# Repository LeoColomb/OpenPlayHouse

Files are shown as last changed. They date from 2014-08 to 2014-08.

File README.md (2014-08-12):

OPH-logo (http://ldworkshop.fr/oph.html)

[Open Play House](http://ldworkshop.fr/oph.html)
=================



About
-----

OpenPlayHouse (OPH for fast typing) is an Open Hardware project launched by LD
Workshop.  
LD Workshop is a maker place where you can lasercut, 3D print and create every
idea you have in mind. Located in France (Saint-Étienne), this workshop has
started in 2013 and is owned by Loyc DESFARGES (me). OPH idea is born because,
as many makers, I have kids who love to play, play, and... play. So I decided
to creat this kind of dollhouse you can make, paint, personnalize, modify...
As it's an open hardware project, feel free to use it, share it and make it
better! Please don't forget to share your improvments, new furnitures,
corrections with me at oph@ldworkshop.fr.

---

OPH is to be made of MDF (Medium Density Fiber wood). Of course, feel free to
try it with any other material. My drawings are optimized for 3 mm thickness
MDF. If you want to cutit in another thikness, you will have to correct size of
every hole where another piece will be inserted.  
As I have a laser-cutter, I designed this project to be lasercut. If you don't
own a laser-cutter, I'm sure you can go to your local maker place, Fab-Lab,
workshop... with the PDF files. Each PDF files is a vector file, it means you
can import it in a vector software to use it with a laser-cutter.  
Some furniture parts must be 3Dprint. Same thing, if you don't have a 3D
printer, I'm sure you can find one locally.  
If you can't find anyone able to lasercut and 3D print, LD Workshop can do it
for you and ship the pieces.

Have fun creating the OPH and I hope your kids will have as much fun playing
with it.

Bill of material
----------------
To create an OPH, you'll need :
* A laser cutter.
* 3 mm MDF (Medium Density Fiber wood) – approx. 1000 mm x 1500 mm.
* 3 mm acrylic (transparent and opaque acrylic are used) – approx. 100 mm x 300
  mm. For some furniture (TV for example, 2mm acrylic is advised but 3mm can
  work too)
* Black cardboard 0,3 to 1mm thick – Approx 100 mm x 100 mm.
* A 3D printer (I used PLA filament but you can do it with other material)
* Some papersand (a thin one: about 80-120)
* Wood glue to assemble MDF parts
* Regular hobby glue (multi-use glue) to assemble acrylic and PLA parts
* for the main door, you will need to drill a very small hole (approx 1mm
  diameter)
* 2 small nails
* Paint, brushes, wall paper... and whatever you want to use to personalize your
  OPH.

Drawings
--------
You can find every needed drawings into the `STL` folder.
OpenPlayHouse.skp file includes 3D views of all part, 2D views and instructions.
To open this file, you'll need Sketchup Make http://www.sketchup.com/download.

* STL files are for 3D printing.
* PDF files contains vector drawings and instructions.

If you see any mistake in those drawings, thank you for letting me know.

License
-------
This project is licensed under __Creative Commons__  
Attribution (BY) - Non commercial - Share Alike

OPH is an Open Hardware Project by Loyc DESFARGES <oph@ldworkshop.fr>

> LD Workshop  
> 4 rue du Grand Gonnet  
> 42000 Saint Etienne  
> France  
> www.ldworkhsop.fr

Special thanks to my wife and kids who are my inspiration, helps and
beta-testers.

Changelog
---------
* __v1.03__: vcs with git, markdownify README, versions by tag
* __v1.02__: add sofa in the .skp file and sofa drawings in the PDF folder.

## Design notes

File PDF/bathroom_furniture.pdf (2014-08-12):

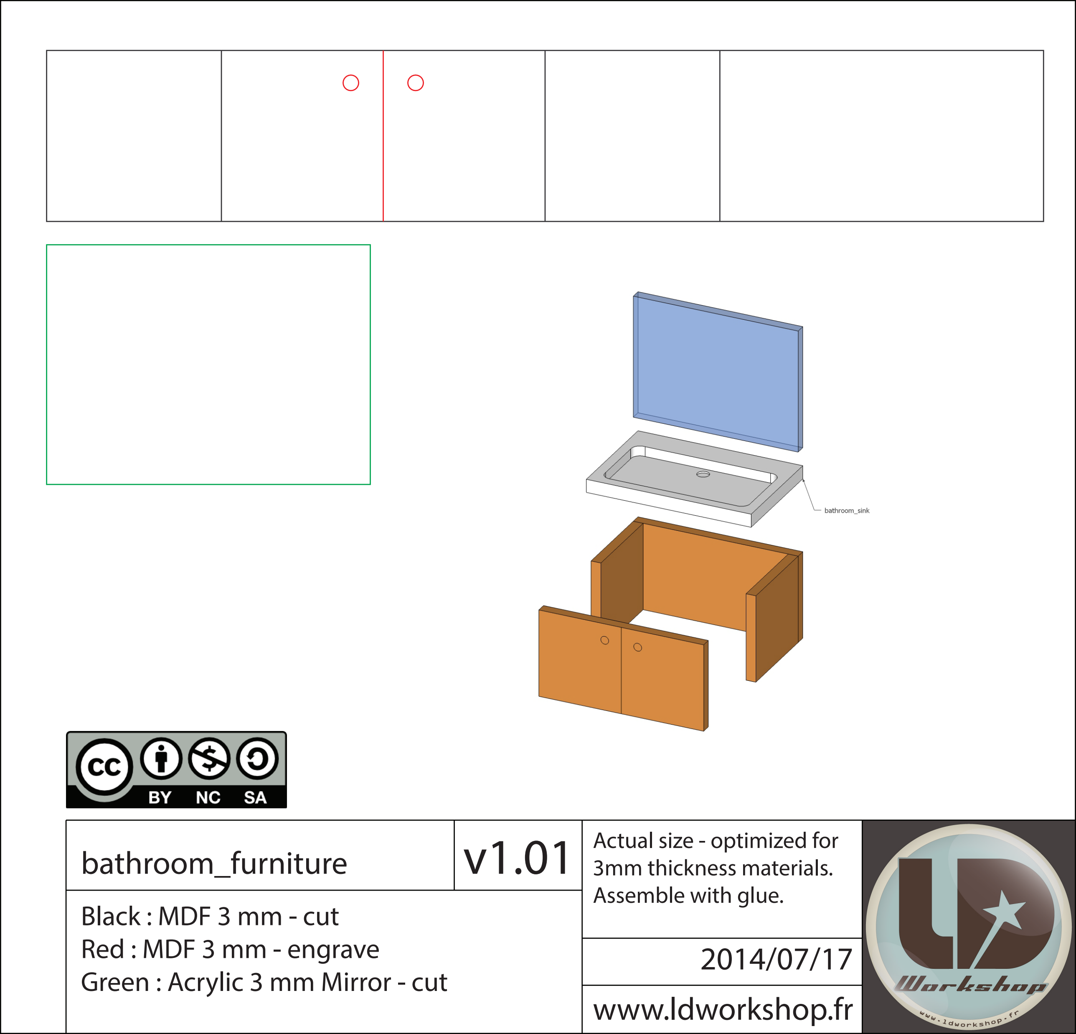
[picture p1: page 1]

bathroom_furniture
Black : MDF 3 mm - cut
Red : MDF 3 mm - engrave
Green : Acrylic 3 mm Mirror - cut

Actual size - optimized for 3mm thickness materials.
Assemble with glue.

www.ldworkshop.fr

2014/07/17

v1.01

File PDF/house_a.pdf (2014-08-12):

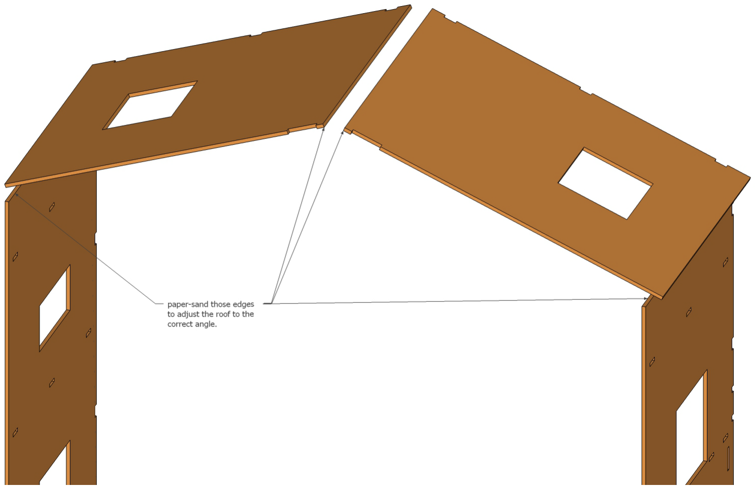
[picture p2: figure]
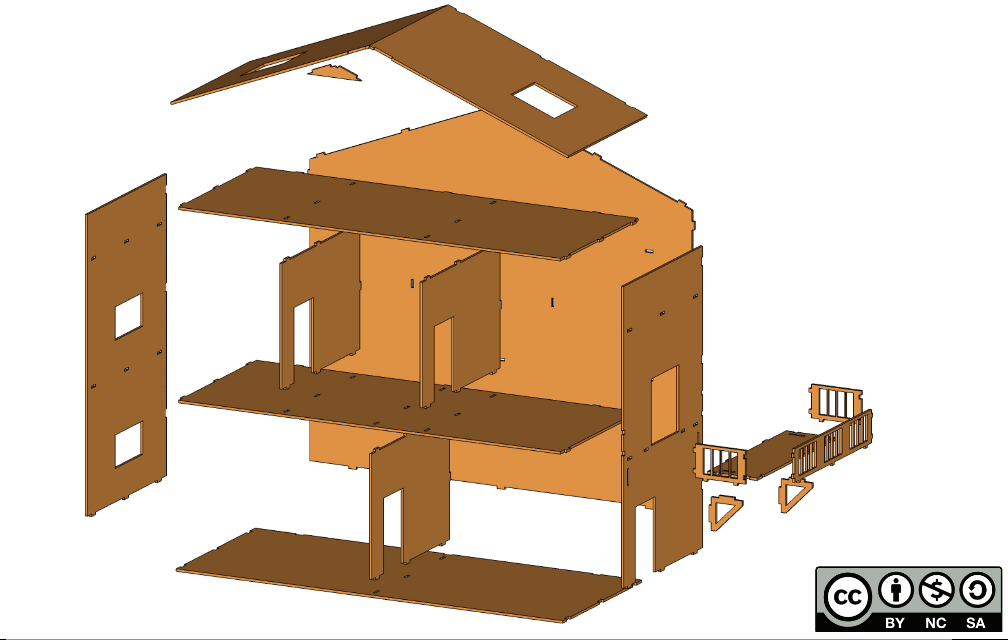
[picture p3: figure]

## house_a

### Black : MDF 3 mm - cut

Actual size - optimized for 3mm thickness materials.
Assemble with glue.

## www.ldworkshop.fr

2014/07/17

v1.01

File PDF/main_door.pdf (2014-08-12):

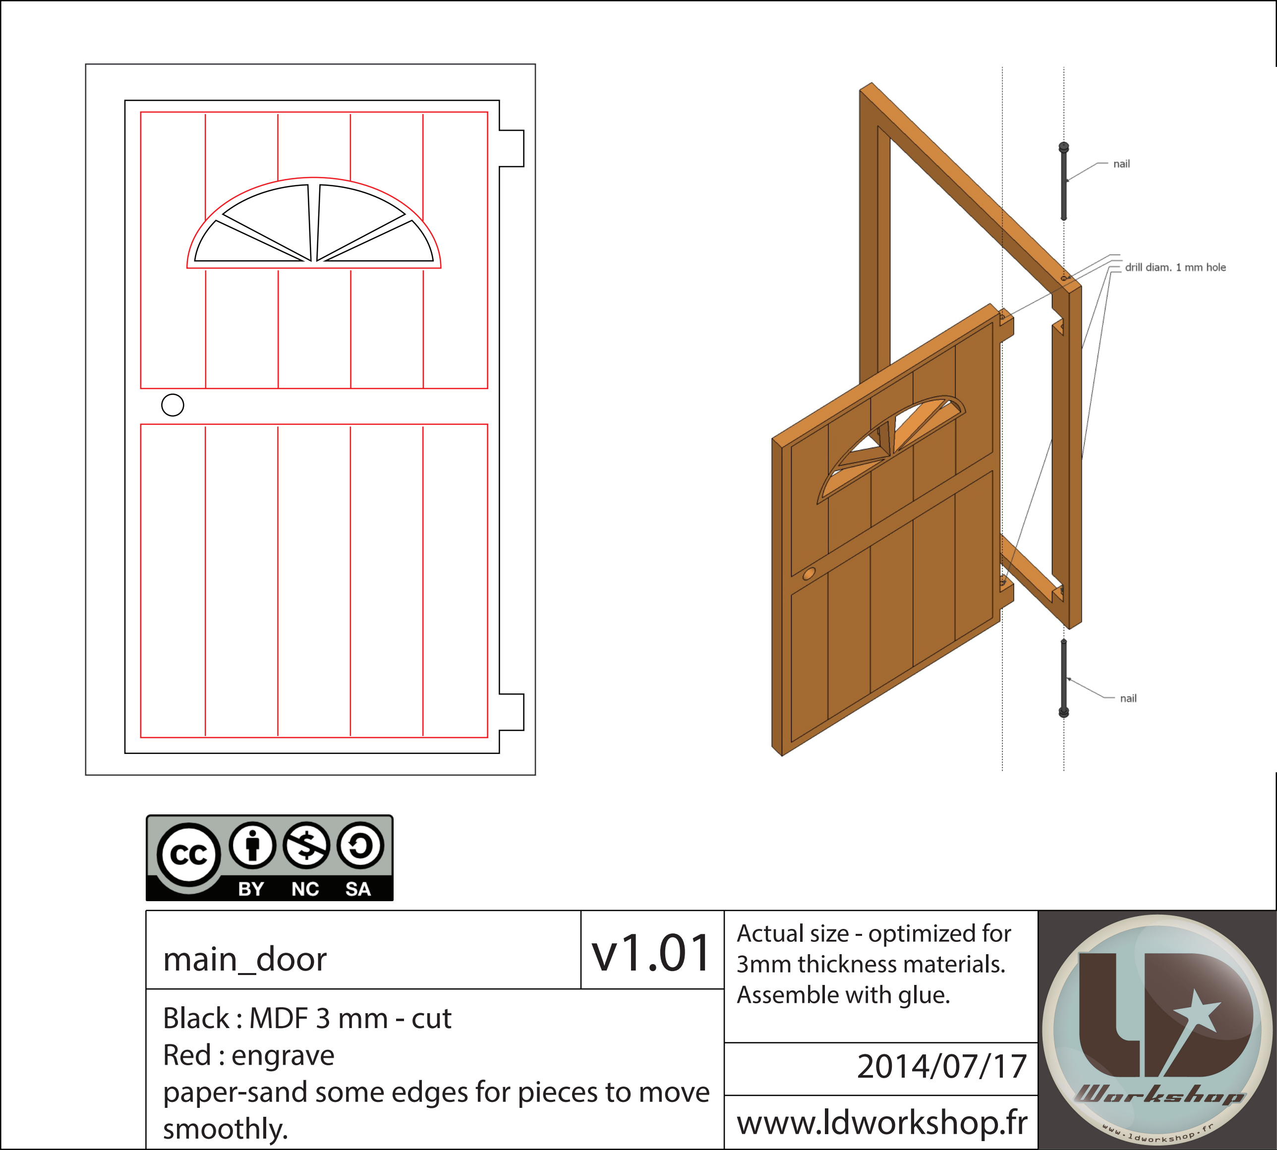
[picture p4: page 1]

main_door
Black : MDF 3 mm - cut
Red : engrave
paper-sand some edges for pieces to move smoothly.

Actual size - optimized for 3mm thickness materials.
Assemble with glue.

www.ldworkshop.fr

2014/07/17

v1.01

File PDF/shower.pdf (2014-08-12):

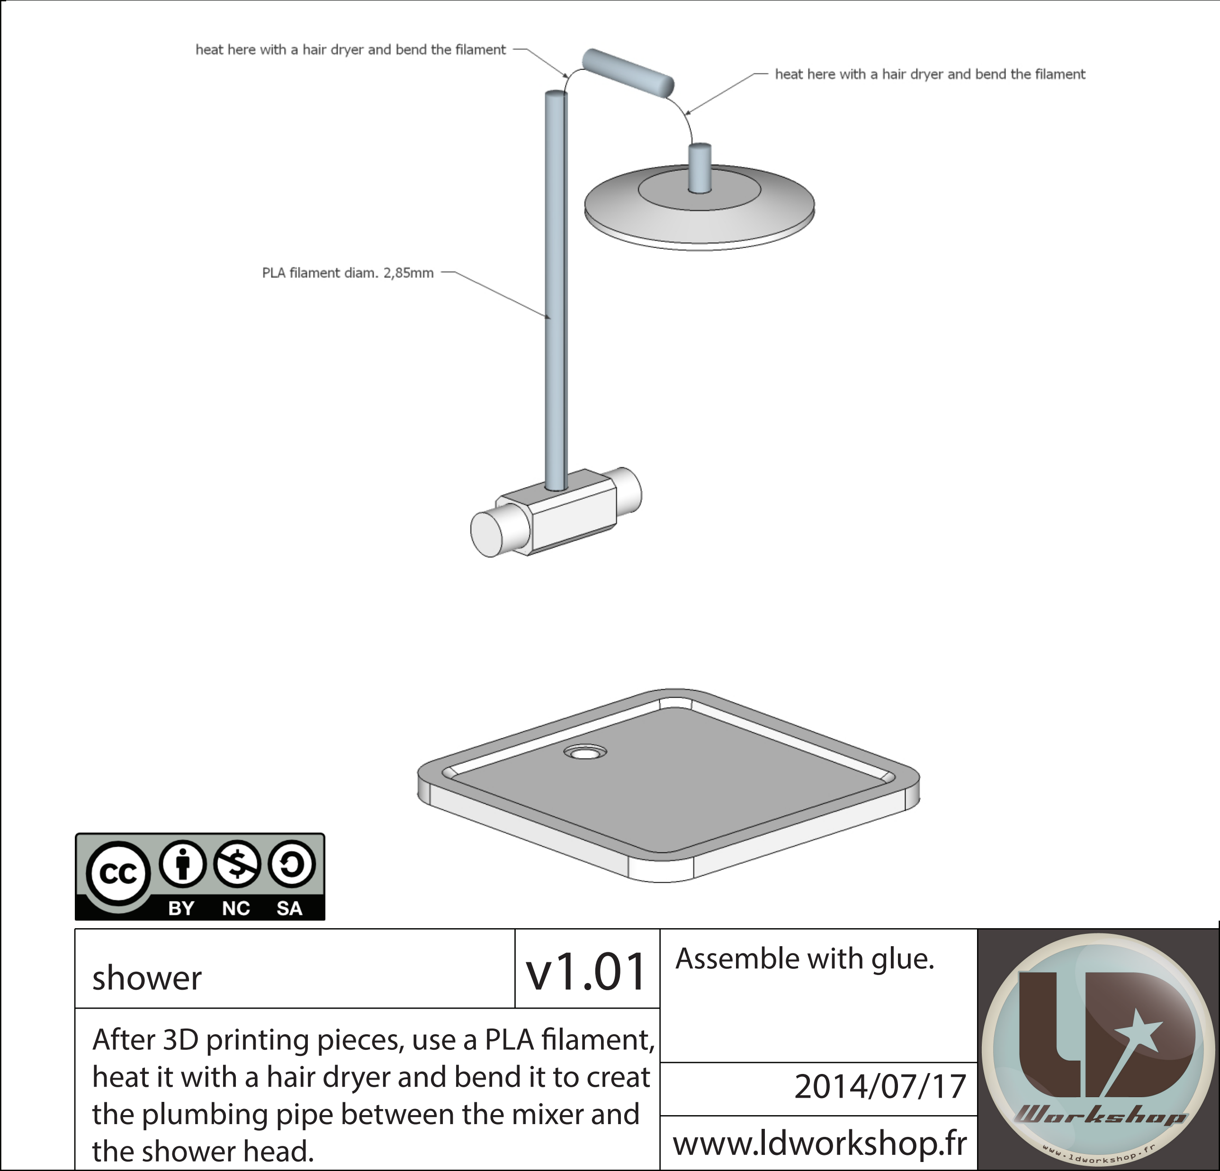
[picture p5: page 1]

shower

www.ldworkshop.fr

2014/07/17

v1.01

After 3D printing pieces, use a PLA lament, heat it with a hair dryer and bend it to creat the plumbing pipe between the mixer and the shower head.

Assemble with glue.

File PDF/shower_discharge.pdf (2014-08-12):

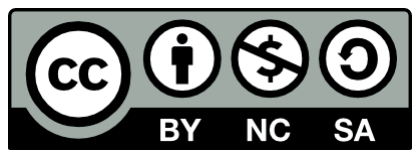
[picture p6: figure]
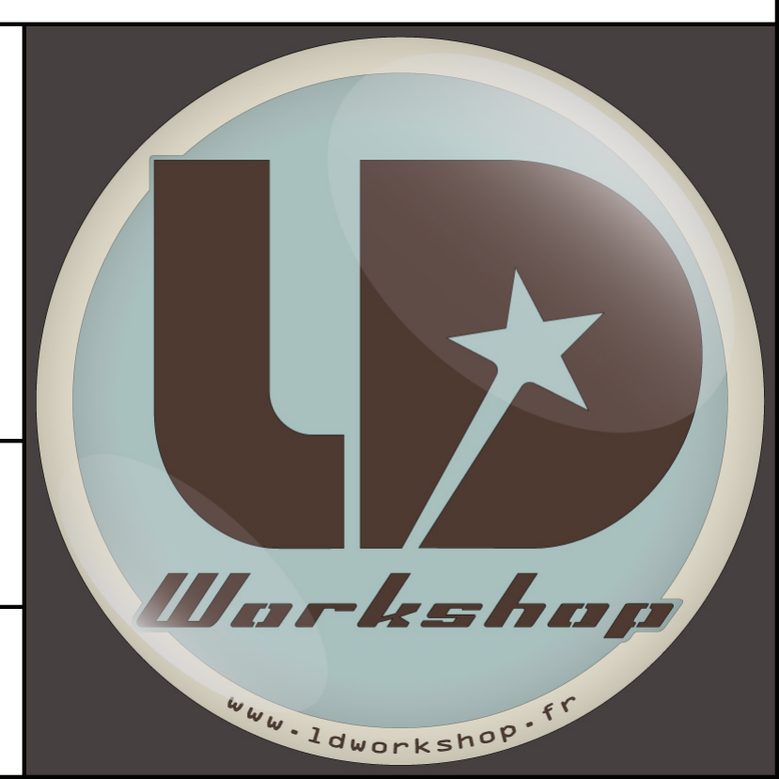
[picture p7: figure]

shower_discharge
Cut it in a black thin cardboard and glue it in the bottom of the shower tray

Assemble with glue.

www.ldworkshop.fr

2014/07/17

v1.01

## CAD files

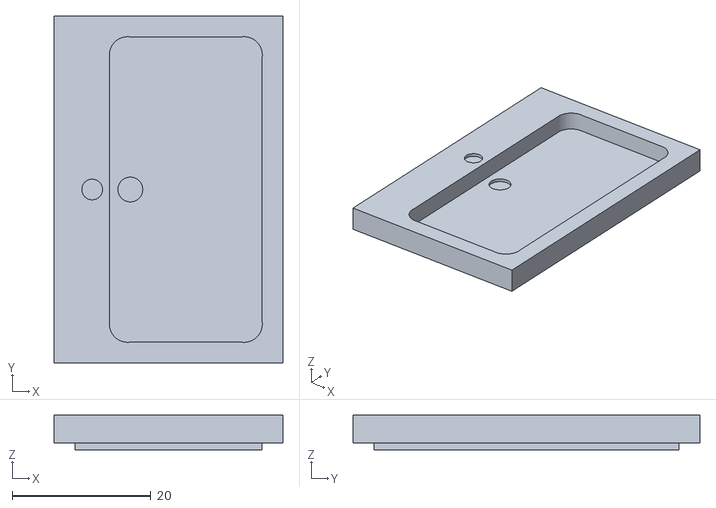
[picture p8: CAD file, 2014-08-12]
STL/bathroom_sink.stl
33.0 x 50.0 x 5.00

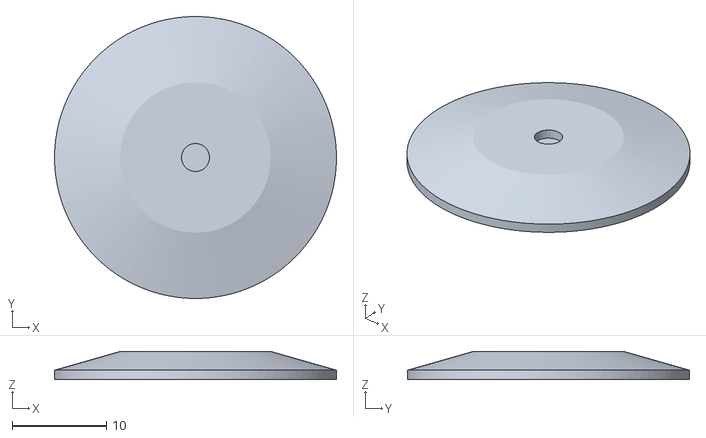
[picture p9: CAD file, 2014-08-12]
STL/shower_head.stl
30.0 x 30.0 x 3.00

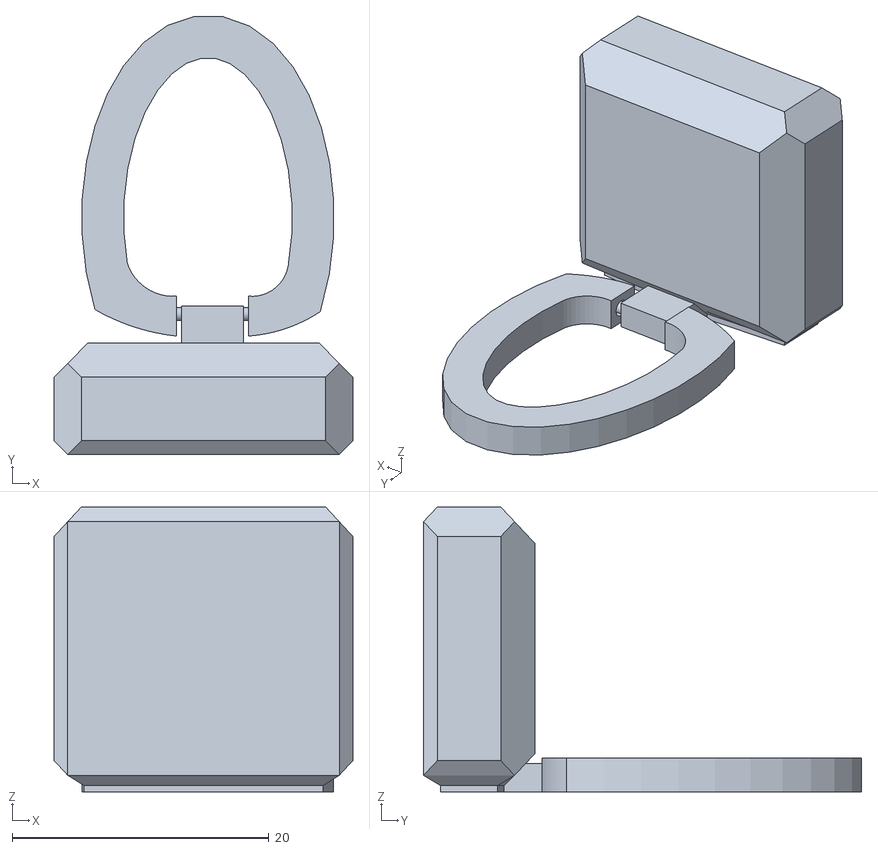
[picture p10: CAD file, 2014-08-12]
STL/toilet_b.stl
23.3 x 34.1 x 22.2

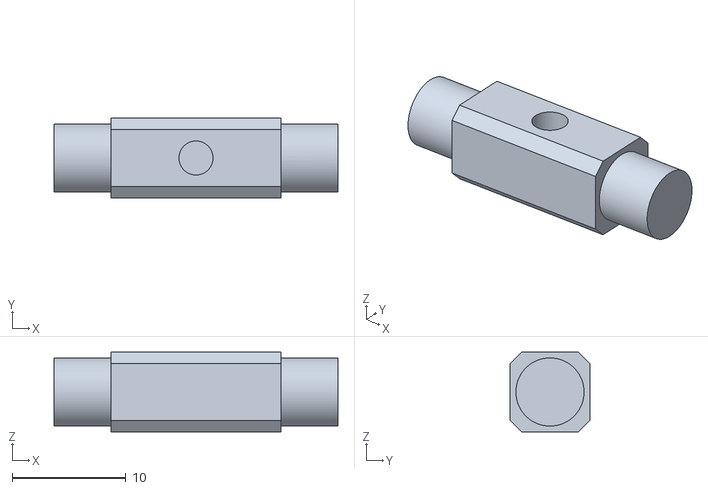
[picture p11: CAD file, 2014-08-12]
STL/shower_mixer.stl
25.0 x 7.00 x 7.00

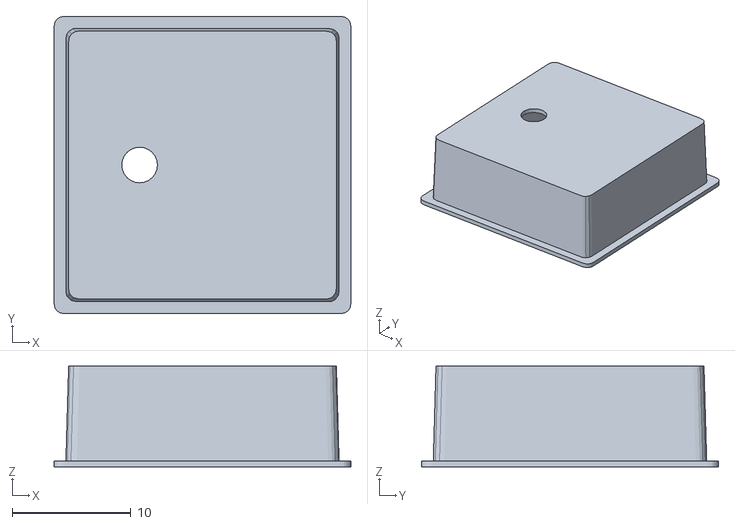
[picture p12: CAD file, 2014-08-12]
STL/kitchen_sink.stl
25.0 x 25.0 x 8.50

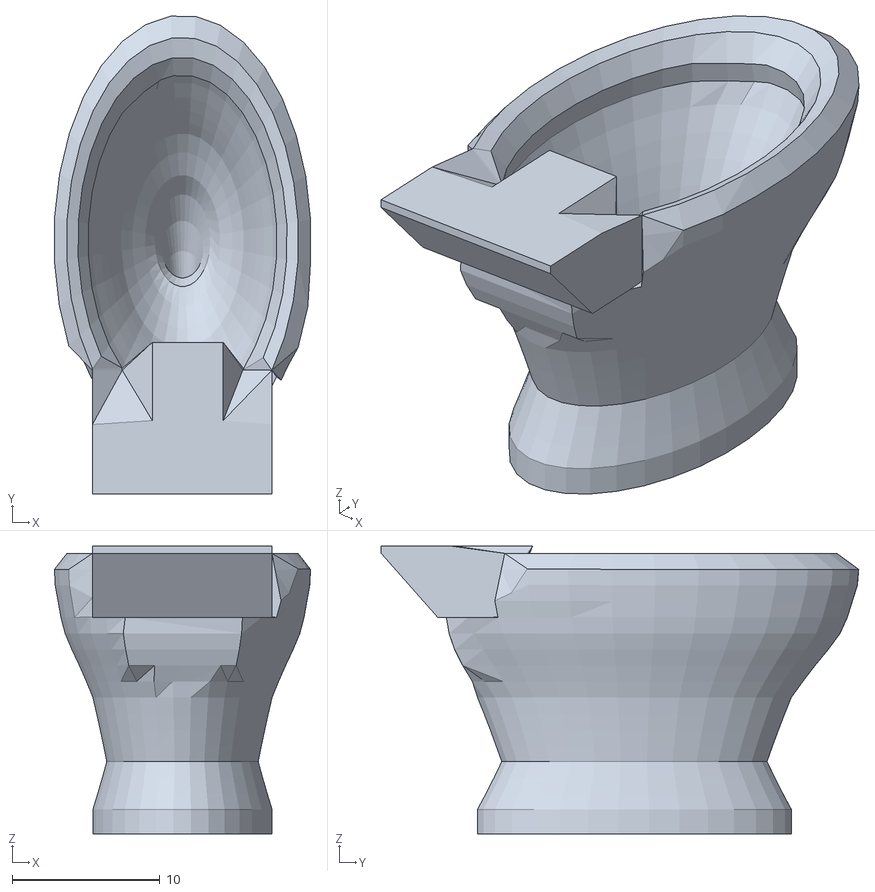
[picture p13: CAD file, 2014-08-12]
STL/toilet_a.stl
17.3 x 32.3 x 19.5

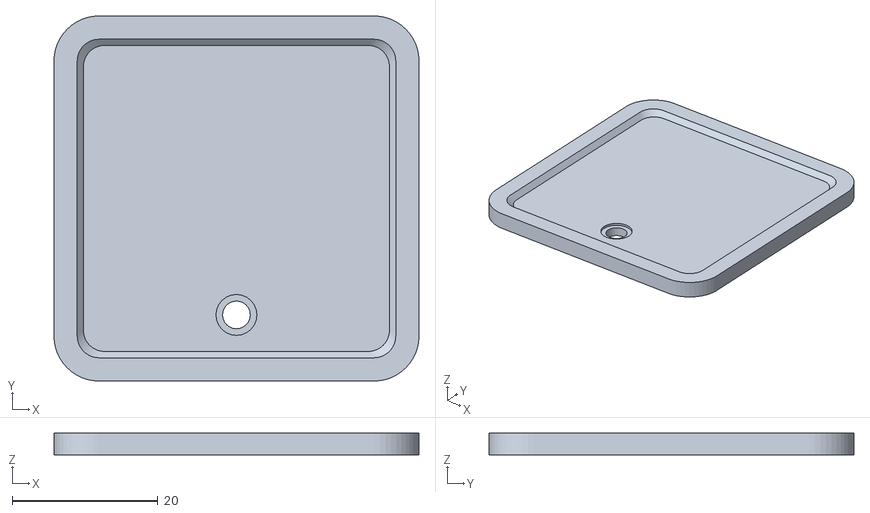
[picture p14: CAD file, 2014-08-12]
STL/shower_tray.stl
50.0 x 50.0 x 3.00

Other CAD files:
OpenPlayHouse.skp

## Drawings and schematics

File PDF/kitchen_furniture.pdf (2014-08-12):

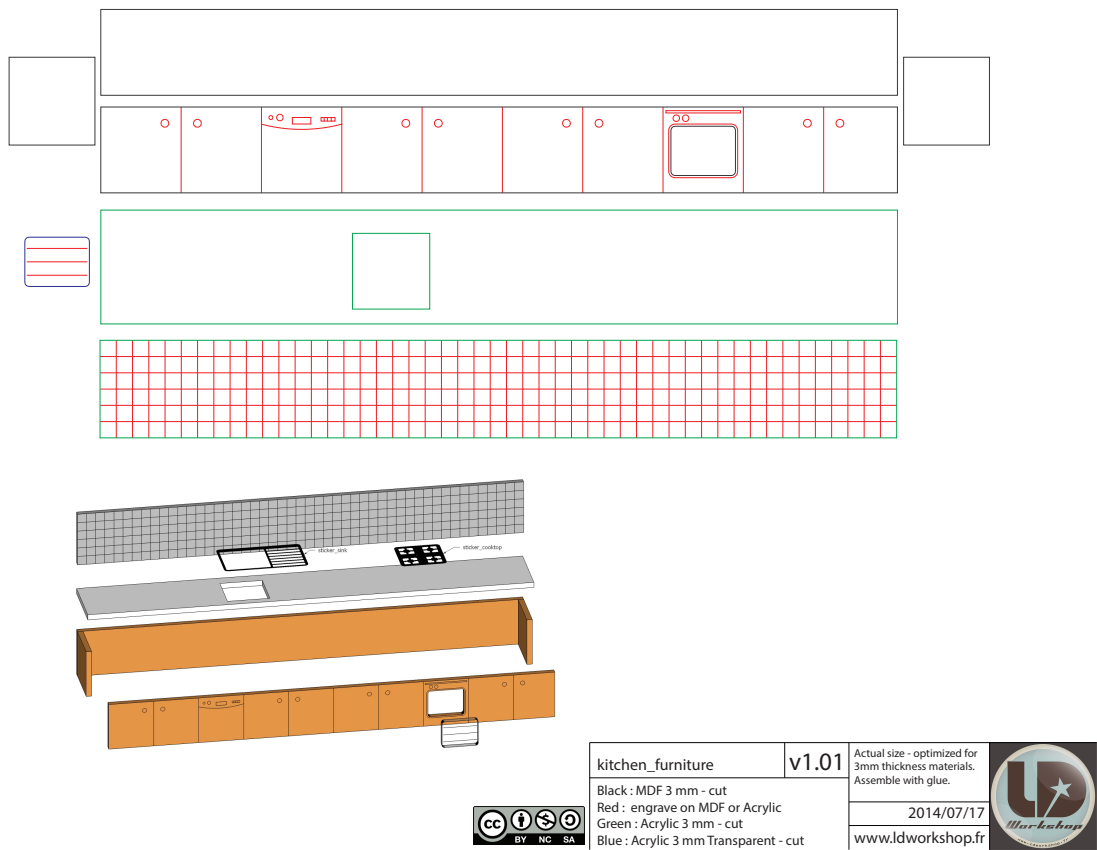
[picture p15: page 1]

Actual size - optimized for
3mm thickness materials.
Assemble with glue.
www.ldworkshop.fr

kitchen_furniture
Black : MDF 3 mm - cut
Red : engrave on MDF or Acrylic
Green : Acrylic 3 mm - cut
Blue : Acrylic 3 mm Transparent - cut

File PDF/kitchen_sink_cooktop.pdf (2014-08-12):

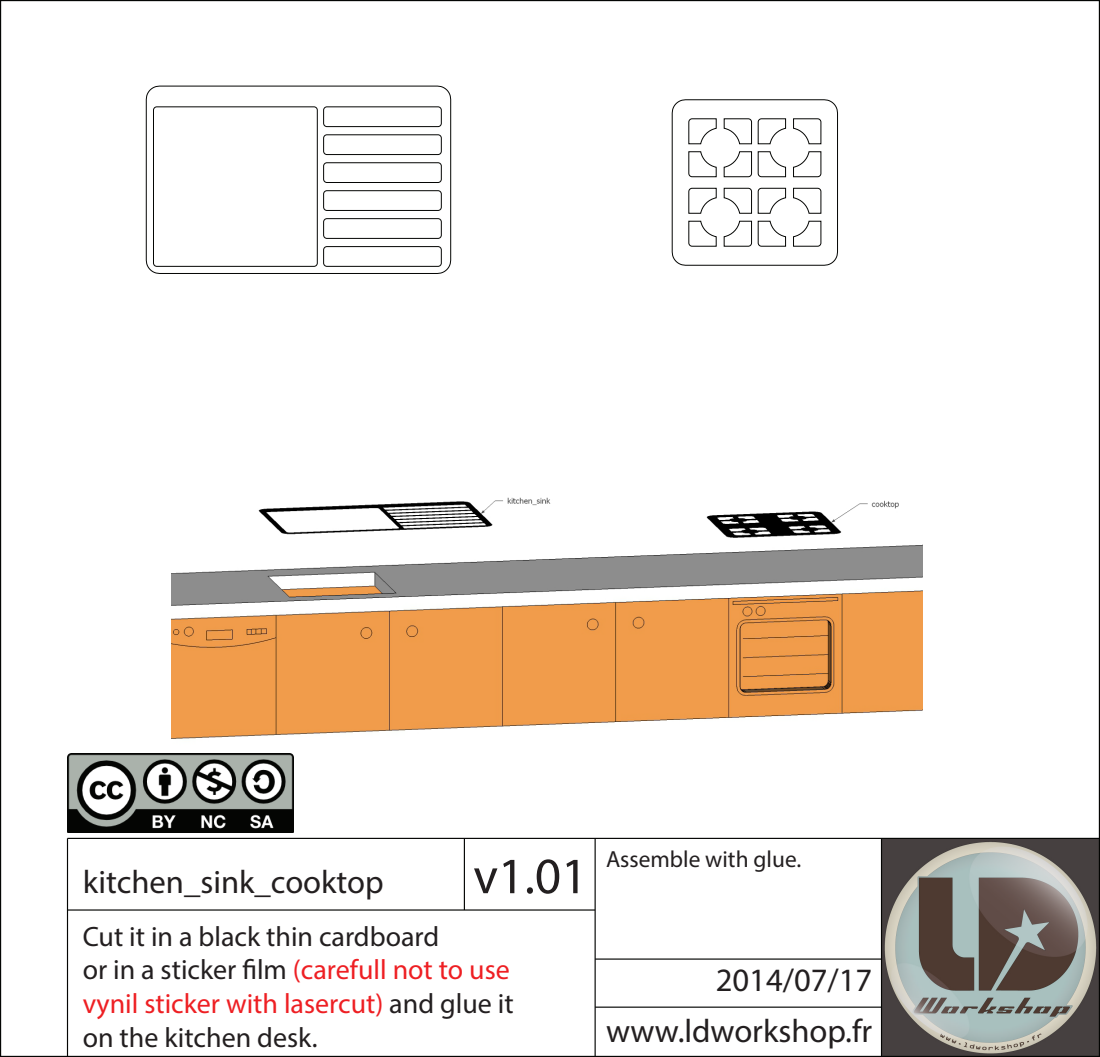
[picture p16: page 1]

Assemble with glue.

kitchen_sink_cooktop
Cut it in a black thin cardboard
or in a sticker lm (carefull not to use
vynil sticker with lasercut) and glue it
on the kitchen desk.

www.ldworkshop.fr

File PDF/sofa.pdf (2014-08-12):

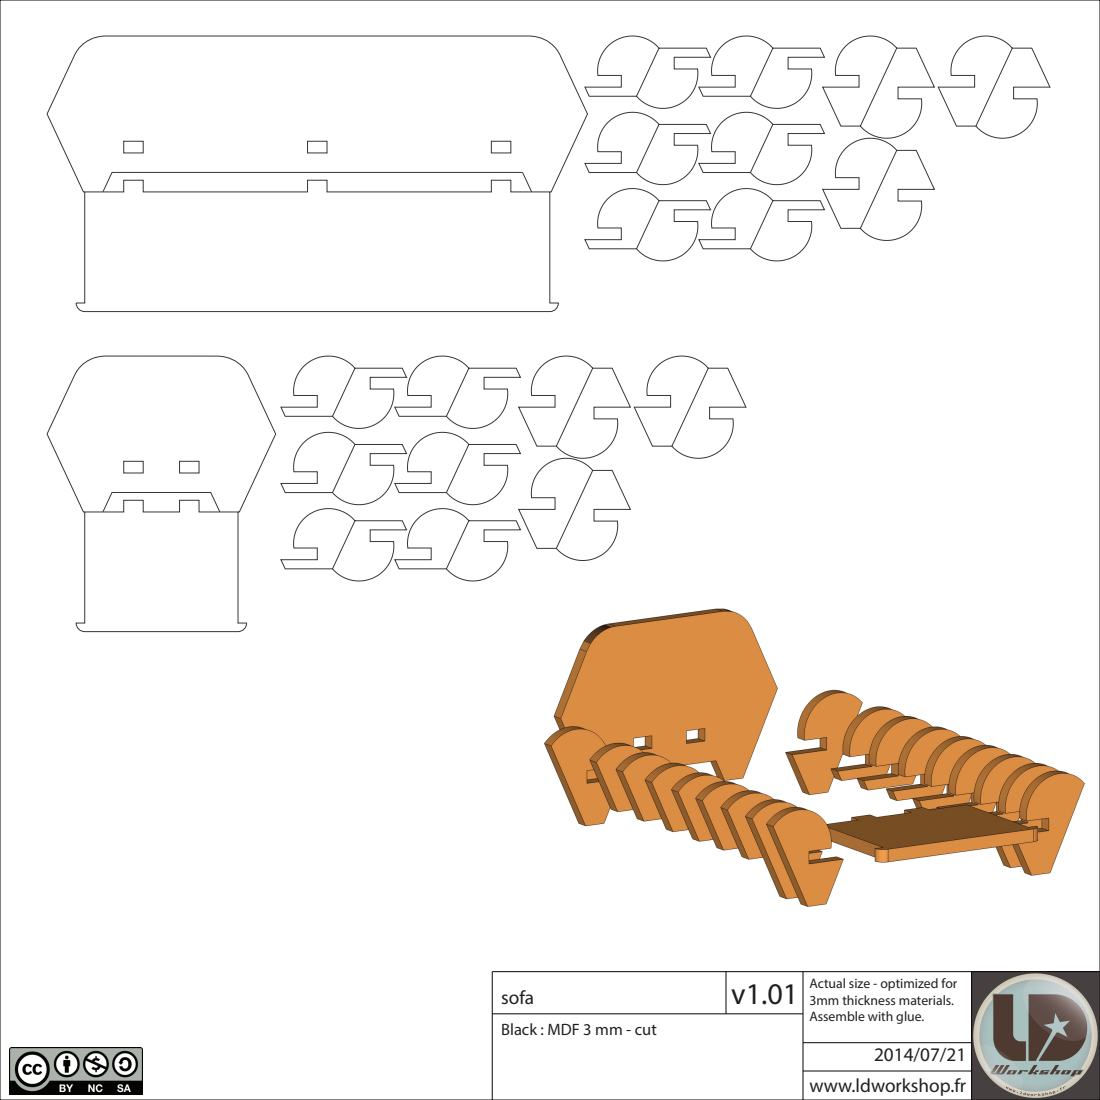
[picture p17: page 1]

Actual size - optimized for
3mm thickness materials.
Assemble with glue.
www.ldworkshop.fr

sofa
Black : MDF 3 mm - cut

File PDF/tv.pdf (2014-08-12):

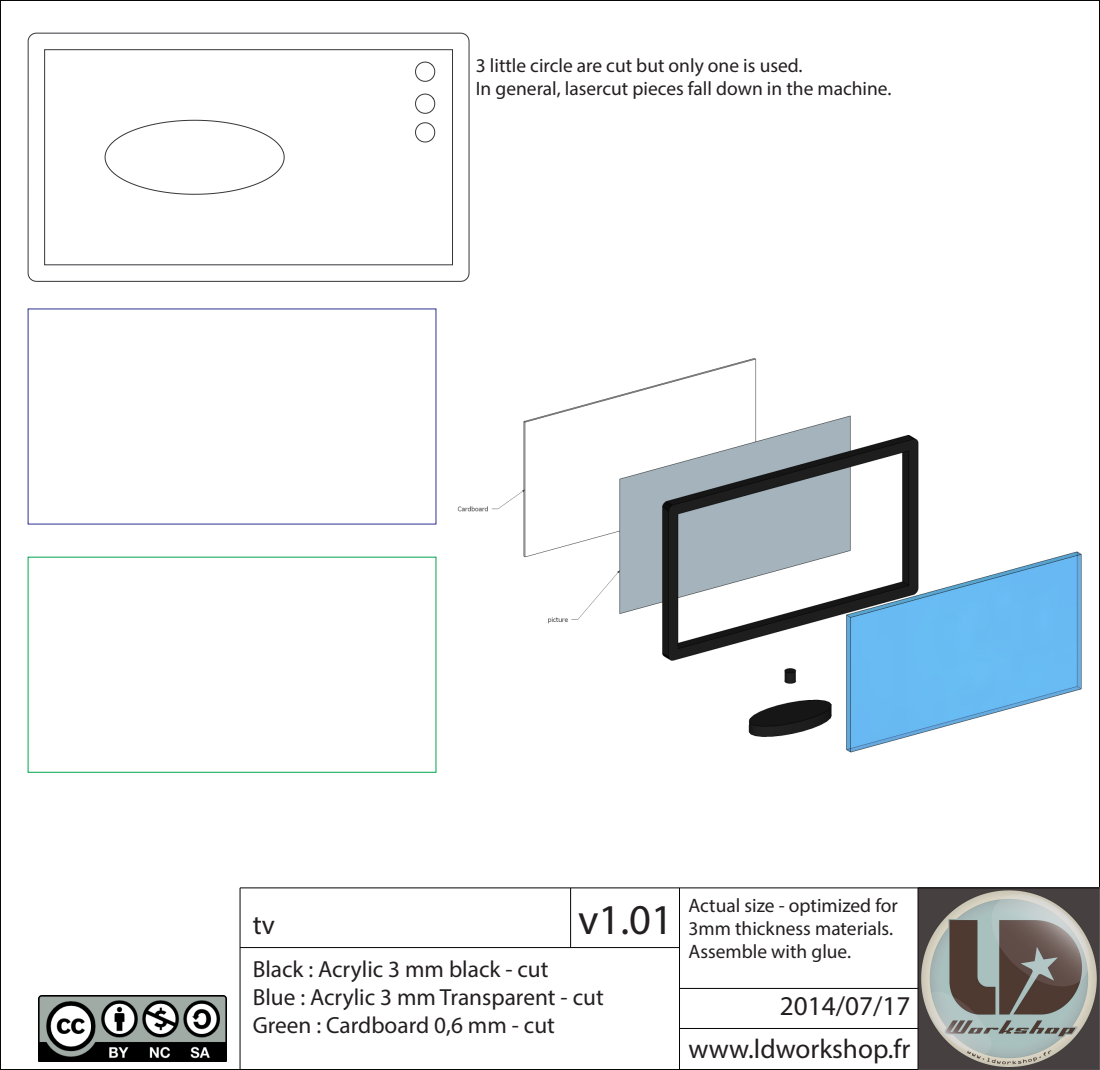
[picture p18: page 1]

3 little circle are cut but only one is used.
In general, lasercut pieces fall down in the machine.

Actual size - optimized for
3mm thickness materials.
Assemble with glue.
www.ldworkshop.fr

Black : Acrylic 3 mm black - cut
Blue : Acrylic 3 mm Transparent - cut
Green : Cardboard 0,6 mm - cut

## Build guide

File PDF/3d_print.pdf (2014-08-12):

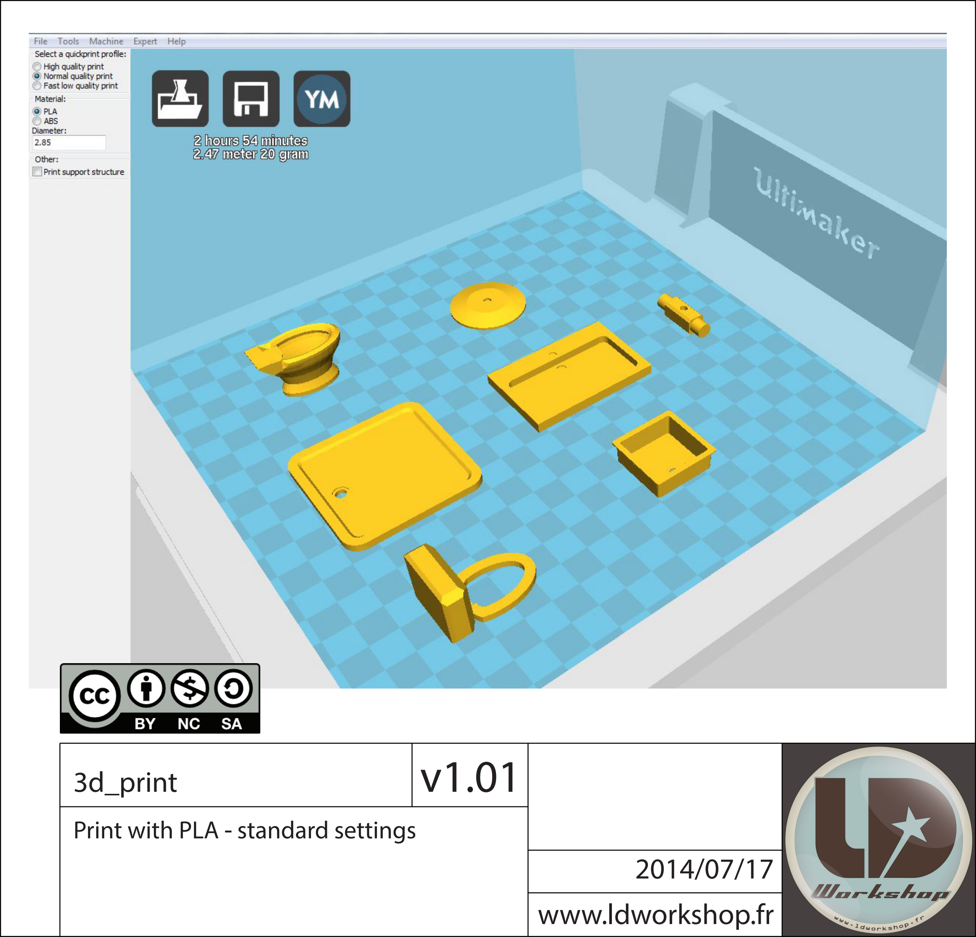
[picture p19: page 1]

3d_print
Print with PLA - standard settings

www.ldworkshop.fr

2014/07/17

v1.01
